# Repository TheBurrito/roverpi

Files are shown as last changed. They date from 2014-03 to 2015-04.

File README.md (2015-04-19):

NOTE: This repository is dead and replaced by the roverpi_hat repo
https://github.com/TheBurrito/roverpi_hat

This repository is being left for reference until the new repository is up and running.

RoverPi - Robotics for the Raspberry Pi
https://github.com/TheBurrito/roverpi

Project website
http://roverpi.com

This repository contains all of the source code for both the Raspberry Pi and
the ATmega2560 on the RoPi expansion board as well as the board design files.

The code is organized into:
-AVR C firmware and libraries in /avr and /common
-Arduino library in /arduino/RoverPi
-Raspberry Pi libraries in /linux and /common
-Eagle Schematic and PCB files in /eagle

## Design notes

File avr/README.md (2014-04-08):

This sub project contains the code for programming the ATmega2560 on the RoverPi

Source code is available at https://github.com/TheBurrito/roverpi

The project is organized into:
-base libraries: ./roverpi, ./include/roverpi
-test programs: ./test
-prewritten firmware: ./firmware

Other folders have varying uses:

./build - Contains all of the intermediate files for compiling
./lib - Contains archived library targets (*.a files)
./bin - Contains all compiled executable code (*.hex files)

***BUILDING

Running make with no parameters will build all targets. Alternatively targets
can be specified by name (see the targets.txt file for targets and info). Make
can also be invoked from any sub directory containing a Makefile. Note that if
targets in the sub directory and below depend on other targets above the current
path that have not been built yet then building will fail.

***UPLOADING

The Makefile build system used here provides an easy mechanism for uploading any
*.hex targets built. A special rule in the form of up-*.hex will use the avrdude
parameters found in avr.mk to upload to the AVR. This rule will also result in
the hex file be compiled if any of the source files are newer.

Use the AVRDUDE_* variables in the avr.mk file to configure how avrdude uploads
the hex file to the board.

- AVRDUDE_PRG specifies the programmer used. This should be "stk500v2" for using
    the Arduino bootloader and a serial port (FTDI).
- AVRDUDE_PORT specifies the port to use for programming

***BUILD SYSTEM (Makefiles)

Build system available at https://github.com/TheBurrito/buildsys

Check there for information regarding the manner in which the makefiles work.

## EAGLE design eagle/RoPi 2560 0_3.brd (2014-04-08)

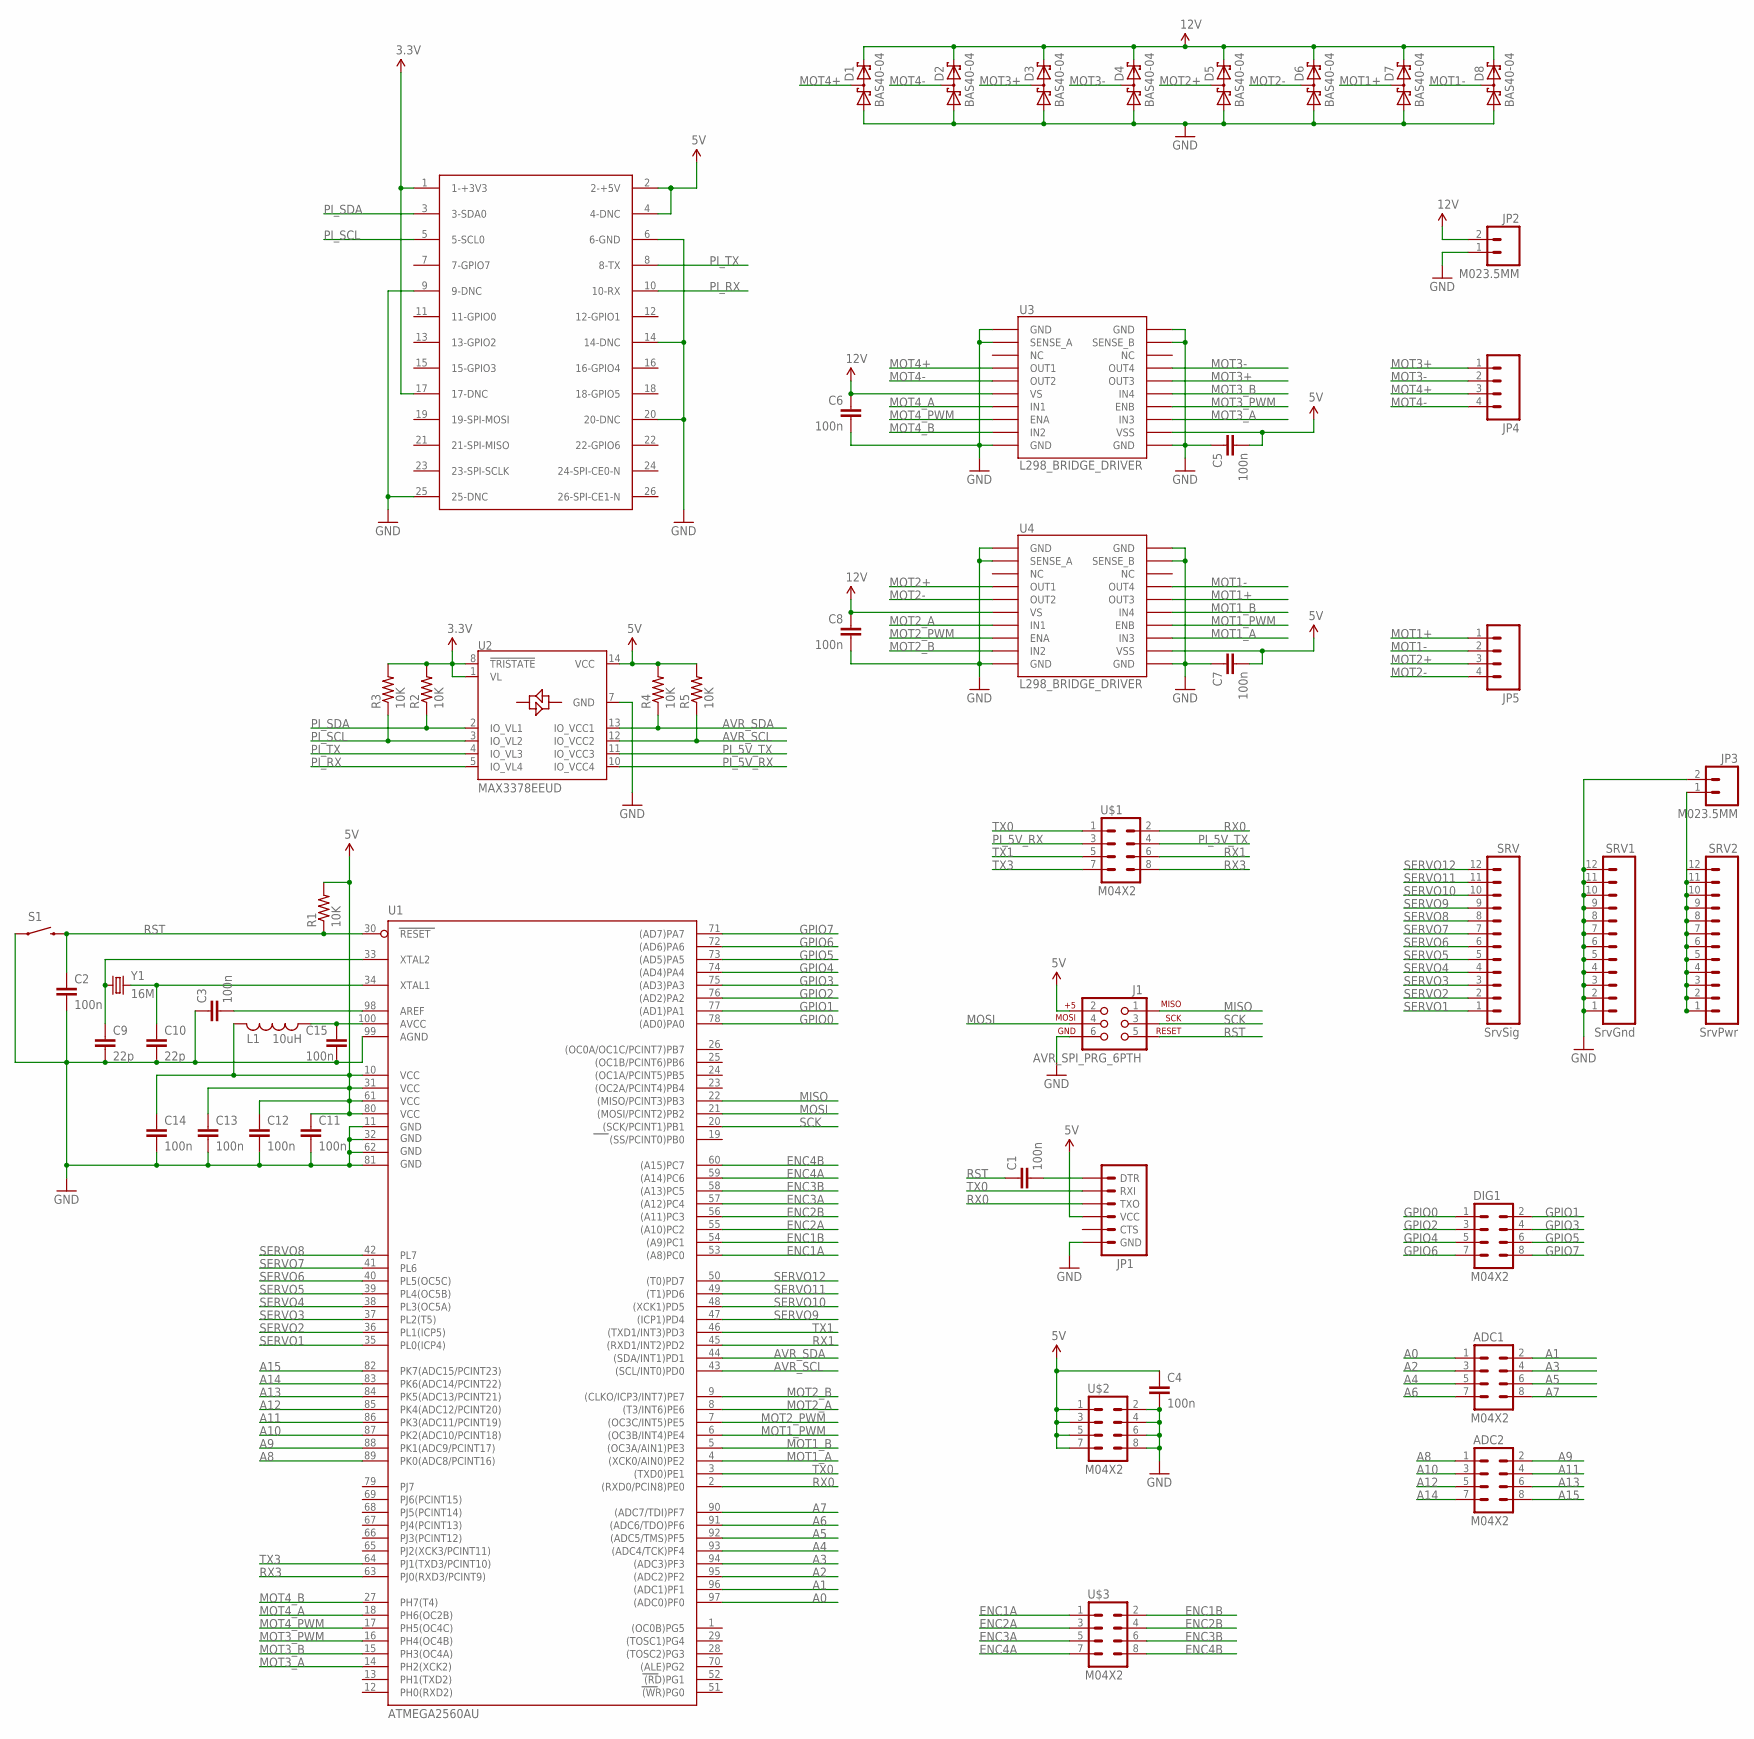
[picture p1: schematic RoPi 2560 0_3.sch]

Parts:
ADC1, ADC2: M04X2; 2X4
C1, C2, C3, C4, C5, C6, C7, C8, C11, C12, C13, C14, C15: 100n; 0603-CAP
C9, C10: 22p; 0603-CAP
D1, D2, D3, D4, D5, D6, D7, D8: BAS40-04; SOT23
DIG1: M04X2; 2X4
J1: AVR_SPI_PRG_6PTH; 2X3
JP1: ARDUINO_SERIAL_PROGRAMSMD; 1X06-SMD
JP2, JP3: M023.5MM; SCREWTERMINAL-3.5MM-2
JP4, JP5: M04SCREW; SCREWTERMINAL-3.5MM-4
L1: 10uH; R0603
PI: RASPBERRY-PI
R1, R2, R3, R4, R5: 10K; 0603-RES
S1: SWITCH-MOMENTARY-2SMD-4; TACTILE_SWITCH_TALL
SRV: SrvSig; 1X12
SRV1: SrvGnd; 1X12
SRV2: SrvPwr; 1X12
U1: ATMEGA2560AU; TQFP100
U2: MAX3378EEUD; TSSOP14
U3, U4: L298_BRIDGE_DRIVER; POWERSO20
U$1, U$2, U$3: M04X2; 2X4
Y1: 16M; HC49UP

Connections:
3.3V: PI.1 (1-+3V3), PI.17 (17-DNC), R2.2, R3.2, U2.1 (VL), U2.8 (!TRISTATE)
5V: C4.1, C5.2, C7.2, C11.1, C12.1, C13.1, C14.1, J1.2, JP1.4 (VCC), L1.2, PI.2 (2-+5V), PI.4 (4-DNC), R1.2, R4.2, R5.2, U1.10 (VCC), U1.31 (VCC1), U1.61 (VCC2), U1.80 (VCC3), U2.14 (VCC), U3.12 (VSS), U4.12 (VSS), U$2.1, U$2.3, U$2.5, U$2.7
A0: ADC1.1, U1.97 ((ADC0)PF0)
A1: ADC1.2, U1.96 ((ADC1)PF1)
A2: ADC1.3, U1.95 ((ADC2)PF2)
A3: ADC1.4, U1.94 ((ADC3)PF3)
A4: ADC1.5, U1.93 ((ADC4/TCK)PF4)
A5: ADC1.6, U1.92 ((ADC5/TMS)PF5)
A6: ADC1.7, U1.91 ((ADC6/TDO)PF6)
A7: ADC1.8, U1.90 ((ADC7/TDI)PF7)
A8: ADC2.1, U1.89 (PK0(ADC8/PCINT16))
A9: ADC2.2, U1.88 (PK1(ADC9/PCINT17))
A10: ADC2.3, U1.87 (PK2(ADC10/PCINT18))
A11: ADC2.4, U1.86 (PK3(ADC11/PCINT19))
A12: ADC2.5, U1.85 (PK4(ADC12/PCINT20))
A13: ADC2.6, U1.84 (PK5(ADC13/PCINT21))
A14: ADC2.7, U1.83 (PK6(ADC14/PCINT22))
A15: ADC2.8, U1.82 (PK7(ADC15/PCINT23))
AREF: C3.2, U1.98 (AREF)
AVR_SCL: R5.1, U1.43 ((SCL/INT0)PD0), U2.12 (IO_VCC2)
AVR_SDA: R4.1, U1.44 ((SDA/INT1)PD1), U2.13 (IO_VCC1)
DTR: C1.2, JP1.1 (DTR)
ENC1A: U1.53 ((A8)PC0), U$3.1
ENC1B: U1.54 ((A9)PC1), U$3.2
ENC2A: U1.55 ((A10)PC2), U$3.3
ENC2B: U1.56 ((A11)PC3), U$3.4
ENC3A: U1.57 ((A12)PC4), U$3.5
ENC3B: U1.58 ((A13)PC5), U$3.6
ENC4A: U1.59 ((A14)PC6), U$3.7
ENC4B: U1.60 ((A15)PC7), U$3.8
GND: C2.2, C3.1, C4.2, C5.1, C6.2, C7.1, C8.2, C9.2, C10.2, C11.2, C12.2, C13.2, C14.2, C15.2, D1.1 (A1), D2.1 (A1), D3.1 (A1), D4.1 (A1), D5.1 (A1), D6.1 (A1), D7.1 (A1), D8.1 (A1), J1.6, JP1.6 (GND), JP2.1, JP3.2, PI.6 (6-GND), PI.9 (9-DNC), PI.14 (14-DNC), PI.20 (20-DNC), PI.25 (25-DNC), S1.A2 (1), SRV1.1, SRV1.2, SRV1.3, SRV1.4, SRV1.5, SRV1.6, SRV1.7, SRV1.8, SRV1.9, SRV1.10, SRV1.11, SRV1.12, U1.11 (GND), U1.32 (GND1), U1.62 (GND2), U1.81 (GND3), U1.99 (AGND), U2.7 (GND), U3.1 (GND), U3.2 (SENSE_A), U3.10 (GND), U3.11 (GND), U3.19 (SENSE_B), U3.20 (GND), U4.1 (GND), U4.2 (SENSE_A), U4.10 (GND), U4.11 (GND), U4.19 (SENSE_B), U4.20 (GND), U$2.2, U$2.4, U$2.6, U$2.8
GPIO0: DIG1.1, U1.78 ((AD0)PA0)
GPIO1: DIG1.2, U1.77 ((AD1)PA1)
GPIO2: DIG1.3, U1.76 ((AD2)PA2)
GPIO3: DIG1.4, U1.75 ((AD3)PA3)
GPIO4: DIG1.5, U1.74 ((AD4)PA4)
GPIO5: DIG1.6, U1.73 ((AD5)PA5)
GPIO6: DIG1.7, U1.72 ((AD6)PA6)
GPIO7: DIG1.8, U1.71 ((AD7)PA7)
MISO: J1.1, U1.22 ((MISO/PCINT3)PB3)
MOSI: J1.4, U1.21 ((MOSI/PCINT2)PB2)
MOT1+: D7.3 (C1A2), JP5.1, U4.16 (OUT3)
MOT1-: D8.3 (C1A2), JP5.2, U4.17 (OUT4)
MOT1_A: U1.4 ((XCK0/AIN0)PE2), U4.13 (IN3)
MOT1_B: U1.5 ((OC3A/AIN1)PE3), U4.15 (IN4)
MOT1_PWM: U1.6 ((OC3B/INT4)PE4), U4.14 (ENB)
MOT2+: D5.3 (C1A2), JP5.3, U4.4 (OUT1)
MOT2-: D6.3 (C1A2), JP5.4, U4.5 (OUT2)
MOT2_A: U1.8 ((T3/INT6)PE6), U4.7 (IN1)
MOT2_B: U1.9 ((CLKO/ICP3/INT7)PE7), U4.9 (IN2)
MOT2_PWM: U1.7 ((OC3C/INT5)PE5), U4.8 (ENA)
MOT3+: D3.3 (C1A2), JP4.1, U3.16 (OUT3)
MOT3-: D4.3 (C1A2), JP4.2, U3.17 (OUT4)
MOT3_A: U1.14 (PH2(XCK2)), U3.13 (IN3)
MOT3_B: U1.15 (PH3(OC4A)), U3.15 (IN4)
MOT3_PWM: U1.16 (PH4(OC4B)), U3.14 (ENB)
MOT4+: D1.3 (C1A2), JP4.3, U3.4 (OUT1)
MOT4-: D2.3 (C1A2), JP4.4, U3.5 (OUT2)
MOT4_A: U1.18 (PH6(OC2B)), U3.7 (IN1)
MOT4_B: U1.27 (PH7(T4)), U3.9 (IN2)
MOT4_PWM: U1.17 (PH5(OC4C)), U3.8 (ENA)
unnamed: JP3.1, SRV2.1, SRV2.2, SRV2.3, SRV2.4, SRV2.5, SRV2.6, SRV2.7, SRV2.8, SRV2.9, SRV2.10, SRV2.11, SRV2.12
unnamed: C15.1, L1.1, U1.100 (AVCC)
PI_5V_RX: U2.10 (IO_VCC4), U$1.3
PI_5V_TX: U2.11 (IO_VCC3), U$1.4
PI_RX: PI.10 (10-RX), U2.5 (IO_VL4)
PI_SCL: PI.5 (5-SCL0), R3.1, U2.3 (IO_VL2)
PI_SDA: PI.3 (3-SDA0), R2.1, U2.2 (IO_VL1)
PI_TX: PI.8 (8-TX), U2.4 (IO_VL3)
RST: C1.1, C2.1, J1.5, R1.1, S1.B2 (2), U1.30 (RESET)
RX0: JP1.3 (TXO), U1.2 ((RXD0/PCIN8)PE0), U$1.2
RX1: U1.45 ((RXD1/INT2)PD2), U$1.6
RX3: U1.63 (PJ0(RXD3/PCINT9)), U$1.8
SCK: J1.3, U1.20 ((SCK/PCINT1)PB1)
SERVO1: SRV.1, U1.35 (PL0(ICP4))
SERVO2: SRV.2, U1.36 (PL1(ICP5))
SERVO3: SRV.3, U1.37 (PL2(T5))
SERVO4: SRV.4, U1.38 (PL3(OC5A))
SERVO5: SRV.5, U1.39 (PL4(OC5B))
SERVO6: SRV.6, U1.40 (PL5(OC5C))
SERVO7: SRV.7, U1.41 (PL6)
SERVO8: SRV.8, U1.42 (PL7)
SERVO9: SRV.9, U1.47 ((ICP1)PD4)
SERVO10: SRV.10, U1.48 ((XCK1)PD5)
SERVO11: SRV.11, U1.49 ((T1)PD6)
SERVO12: SRV.12, U1.50 ((T0)PD7)
TX0: JP1.2 (RXI), U1.3 ((TXD0)PE1), U$1.1
TX1: U1.46 ((TXD1/INT3)PD3), U$1.5
TX3: U1.64 (PJ1(TXD3/PCINT10)), U$1.7
V_BATT: C6.1, C8.1, D1.2 (C2), D2.2 (C2), D3.2 (C2), D4.2 (C2), D5.2 (C2), D6.2 (C2), D7.2 (C2), D8.2 (C2), JP2.2, U3.6 (VS), U4.6 (VS)
XTAL1: C10.1, U1.34 (XTAL1), Y1.2
XTAL2: C9.1, U1.33 (XTAL2), Y1.1

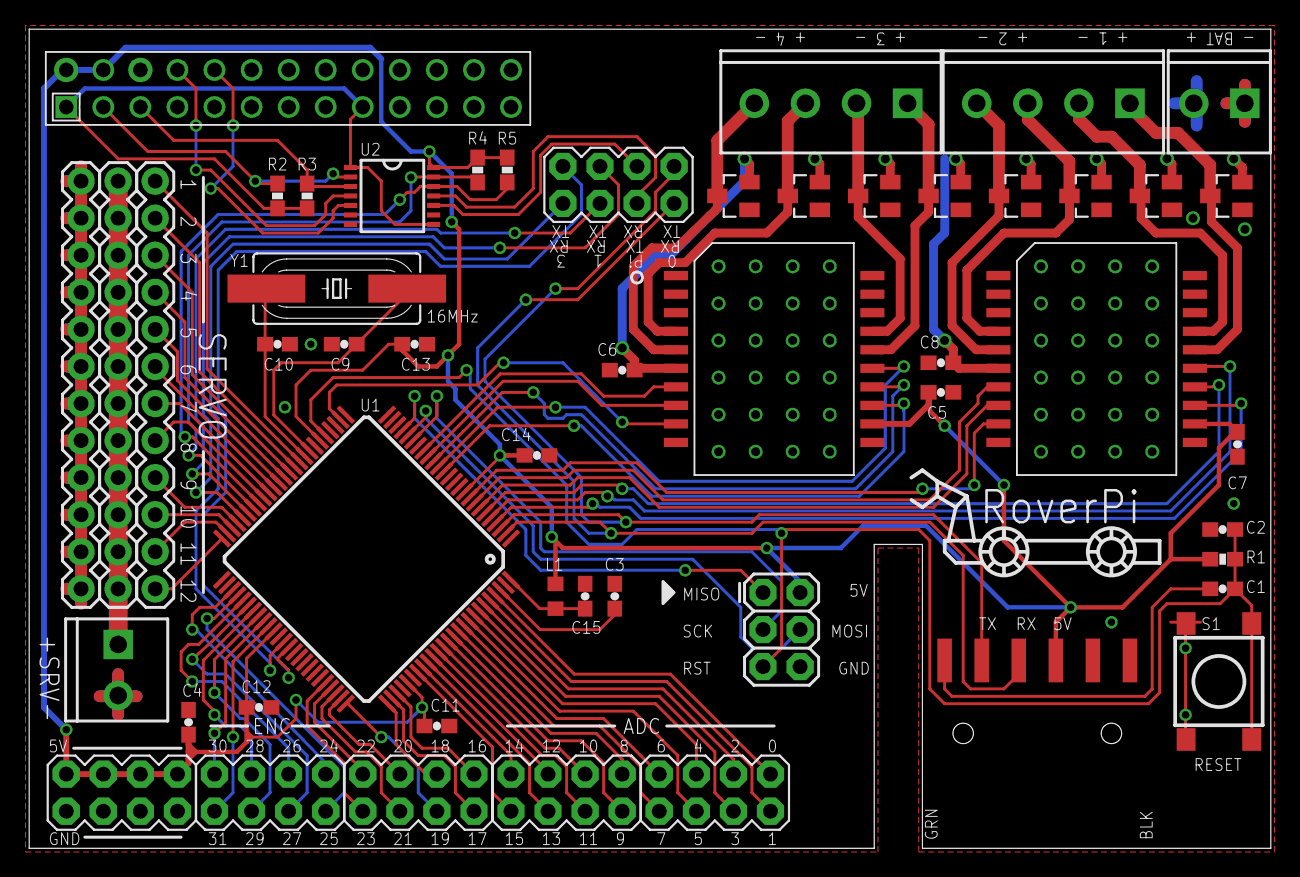
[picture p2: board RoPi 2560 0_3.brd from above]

Board: 2 copper layers, 85.1 x 56.1 mm, 51 parts (0 on the bottom side), 92 nets.

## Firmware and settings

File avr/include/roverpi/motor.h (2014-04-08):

/**

**/

#ifndef motor_h_
#define motor_h_

#include "base.h"
//#include <stdint.h>

#define DIV_OFF  0
#define DIV_1    1
#define DIV_8    2
#define DIV_64   3
#define DIV_256  4
#define DIV_1024 5

#ifndef MOTOR_PRESCALE
#define MOTOR_PRESCALE DIV_1
#endif

#ifndef MOTOR_FREQ
#define MOTOR_FREQ 10000
#endif

#if MOTOR_PRESCALE == DIV_1
#define MOTOR_N 1
#elif MOTOR_PRESCALE == DIV_8
#define MOTOR_N 8
#elif MOTOR_PRESCALE == DIV_64
#define MOTOR_N 64
#elif MOTOR_PRESCALE == DIV_256
#define MOTOR_N 256
#elif MOTOR_PRESCALE == DIV_1024
#define MOTOR_N 1024
#elif MOTOR_PRESCALE == DIV_OFF
#define MOTOR_N 0
#endif

#ifndef MOTOR_N
#error MOTOR_N could not be set. Ensure a proper value is set for MOTOR_PRESCALE
#define MOTOR_N 0
#endif

#if MOTOR_N == 0
#define MOTOR_TOP 0
#define MOTOR_TRUE_FREQ 0
#else
#define MOTOR_TOP ( F_CPU / (2 * MOTOR_N * MOTOR_FREQ) )
#define MOTOR_TRUE_FREQ ( F_CPU / (2 * MOTOR_N * MOTOR_TOP) )
#endif

#define MOTOR_TCCRnA 43
#define MOTOR_TCCRnB ( 16 | MOTOR_PRESCALE )

#define MOTOR1_PORT PORTE
#define MOTOR1_DDR DDRE
#define MOTOR1_PA PE2
#define MOTOR1_PB PE3
#define MOTOR1_PPWM PE4
#define MOTOR1_VAL OCR3B

#define MOTOR2_PORT PORTE
#define MOTOR2_DDR DDRE
#define MOTOR2_PA PE6
#define MOTOR2_PB PE7
#define MOTOR2_PPWM PE5
#define MOTOR2_VAL OCR3C

#define MOTOR3_PORT PORTH
#define MOTOR3_DDR DDRH
#define MOTOR3_PA PH2
#define MOTOR3_PB PH3
#define MOTOR3_PPWM PH4
#define MOTOR3_VAL OCR4B

#define MOTOR4_PORT PORTH
#define MOTOR4_DDR DDRH
#define MOTOR4_PA PH6
#define MOTOR4_PB PH7
#define MOTOR4_PPWM PH5
#define MOTOR4_VAL OCR4C

typedef enum {
	COAST,
	FORWARD,
	REVERSE,
	BRAKE
} MotorMode;

void motor_init();

void set_motor(uint8_t num, MotorMode mode, uint16_t val);

#endif

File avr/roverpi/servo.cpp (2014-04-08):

#include <roverpi/base.h>
#include <roverpi/servo.h>

#include <avr/interrupt.h>

namespace roverpi {

#define SERVO_COUNT 12

typedef struct {
	volatile uint8_t * port;
	unsigned int ticks;
	uint8_t clearmask, setmask;
	uint16_t min_ticks, max_ticks;
} servo_t;

servo_t _servo[SERVO_COUNT];

static volatile int8_t _channel;

ISR(TIMER5_COMPA_vect) 
{
	if (_channel < 0) {
		TCNT5 = 0; // channel set to -1 indicated that refresh interval completed so reset the timer 
	} else {
		if (_servo[_channel].ticks > 0) { 
			//digitalWrite( SERVO(timer,Channel[timer]).Pin.nbr,LOW); // pulse this channel low if activated
			*(_servo[_channel].port) &= _servo[_channel].clearmask;
		}
	}

	_channel++;    // increment to the next channel
	
	if (_channel < SERVO_COUNT) {
		if (_servo[_channel].ticks > 0) {
			OCR5A = TCNT5 + _servo[_channel].ticks;
			*(_servo[_channel].port) |= _servo[_channel].setmask;
		} else {
			OCR5A = TCNT5 + 2000;
		}
	} else { 
		// finished all channels so wait for the refresh period to expire before starting over 
		if (((unsigned)TCNT5) + 4 < 40000) {  // allow a few ticks to ensure the next OCR1A not missed
			OCR5A = 40000;  
		} else  {
			OCR5A = TCNT5 + 4;  // at least REFRESH_INTERVAL has elapsed
		}
		
		_channel = -1; // this will get incremented at the end of the refresh period to start again at the first channel
	}
}

void initISR() {
	TCCR5A = 0;             // normal counting mode 
    TCCR5B = _BV(CS51);     // set prescaler of 8  
    TCNT5 = 0;              // clear the timer count 
    TIFR5 = _BV(OCF5A);     // clear any pending interrupts; 
    TIMSK5 =  _BV(OCIE5A) ; // enable the output compare interrupt
}

void servo_init() {
	volatile uint8_t *ports[] = {&PORTL, &PORTD};
	
	for (uint8_t i = 0; i < SERVO_COUNT; ++i) {
		_servo[i].port = ports[i / 8];
		_servo[i].ticks = 0;
		_servo[i].min_ticks = 2000;
		_servo[i].max_ticks = 4000;
		_servo[i].setmask = 1<<(i % 8);
		
		if (i > 7) {
			_servo[i].setmask = _servo[i].setmask << 4;
		}
		
		_servo[i].clearmask = ~_servo[i].setmask;
	}
	
	_channel = -1;
	
	PORTL = 0;
	DDRL = 0xFF;
	
	PORTD &= 0xF;
	DDRD |= 0x0F;
	
	initISR();
}

inline
void servo_ticks(uint8_t num, uint16_t ticks) {
	if (ticks < _servo[num].min_ticks) ticks = _servo[num].min_ticks;
	if (ticks > _servo[num].max_ticks) ticks = _servo[num].max_ticks;
	
	cli();
	_servo[num].ticks = ticks;
	sei();
}

void servo_angle(uint8_t num, uint8_t angle) {
	servo_ticks(num, (uint16_t)map(angle, 0, 180, _servo[num].min_ticks, _servo[num].max_ticks));
}

void servo_angle_x10(uint8_t num, uint16_t angx10) {
	servo_ticks(num, (uint16_t)map(angx10, 0, 1800, _servo[num].min_ticks, _servo[num].max_ticks));
}

void servo_us(uint8_t num, uint16_t us) {
	servo_ticks(num, us * 2);
}

void servo_coast(uint8_t num) {
_servo[num].ticks = 0;
}

void servo_range_us(uint8_t num, uint16_t min, uint16_t max) {
	_servo[num].min_ticks = min * 2;
	_servo[num].max_ticks = max * 2;
}

} //namespace ropi

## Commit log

2014-03-13 Adding eagle files for RoPi expansion board
    [RoPi 2560.brd, RoPi 2560.sch]
2014-03-15 Removed 5V <-> 3V3 selector jumper as an ATmega2560 running at 16MHz can only be supplied 5V
    [RoPi 2560.brd, RoPi 2560.sch]
2014-03-19 Leaving 2nd revision board as-is; will not be ordering 0.2 board.
    0.3 is a complete re-routing and layout adjustment. The ATmega has been
    moved closer to the bottom left corner. The slot for the camera cable has
    been adjusted to the left a bit to better sit squarely over the connector.
    The reset switch and passives have been moved over the ethernet connector
    adjacent to the FTDI header. The ISP header has also been moved away from
    the edge to allow a normal IDC connector to fit.
    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
    [RoPi 2560 0_3.brd, RoPi 2560 0_3.sch, RoPi 2560.brd]
2014-04-08 Updated name to RoverPi, moved arduino library into /arduino/RoverPi
    [RoPi 2560 0_3.brd, RoPi 2560 0_3.sch]

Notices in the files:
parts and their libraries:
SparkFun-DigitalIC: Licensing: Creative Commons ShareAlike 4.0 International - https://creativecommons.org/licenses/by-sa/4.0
